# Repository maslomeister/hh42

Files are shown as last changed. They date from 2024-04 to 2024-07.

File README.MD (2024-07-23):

# hh42

Беспроводная эрго сплит клавиатура заточенная под руки владельца репозитория, MX LP и [ZMK](https://zmk.dev/).

Спасибо [Corne](https://github.com/foostan/crkbd) за вдохновление.

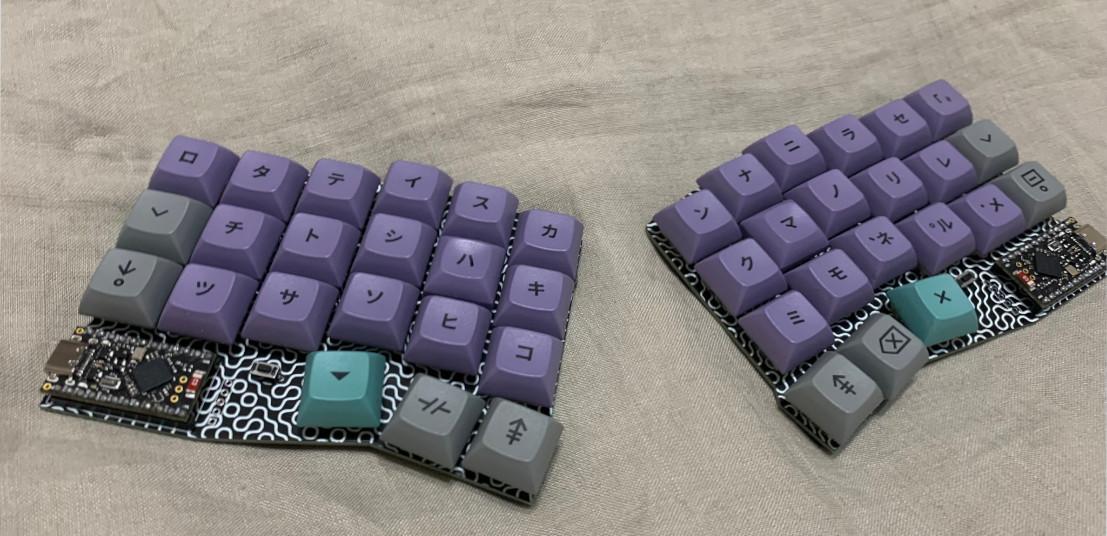
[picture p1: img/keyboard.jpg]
keyboardimage


# Гербер файлы

Скачать гербер файлы ПЦБ можно [ТУТ](https://github.com/maslomeister/hh42/blob/main/pcb/production/hh42.zip)

# Стоимость сборки

| Предмет | Цена в $ | Комментарий | Ссылка |
| --- | --- | --- | --- |
| ПЦБ | 25 | Цена за 5 комплектов | https://aliexpress.ru/item/1005006573905744.html |
| MX LP свитчи | 27 | Цена за 60 штук | https://aliexpress.ru/item/1005006328228130.html |
| Ножки | 4.6 | Цена за 100 штук | https://aliexpress.ru/item/32963141746.html |
| SuperMini | 4.8 | Клон nice nano 2.0 | https://aliexpress.ru/item/1005006035267231.html |
| Диоды | 0.85 | Цена за 100 штук | https://aliexpress.ru/item/32849879904.html |
| PCM12SMTR переключатель | 4 | Цена за 5 штук | https://aliexpress.ru/item/1005005366298406.html |
| Reset кнопка | 1.5 | 4.3ММ; Цена за 100 штук | https://aliexpress.ru/item/32882161197.html |
| Сокеты для контроллера  | 1.9 | Цена за 100 штук | https://aliexpress.ru/item/32980406694.html |
| Пины для контроллера | 4.3 | Цена за 100 штук | https://aliexpress.ru/item/32858430771.html |
| Аккумулятор 110 mah | 4.2 | - | https://www.ozon.ru/product/akkumulyator-dlya-videoregistratora-akb-batareya-3-7v-130mah-5x12x30-li-pol-2-provoda-501230-1047383524 |
| Итог за 1 клавиатуру | <!--5+27+4.6/100*30+4/8+4/8+0.85/100*42+4/5*2+1.5/10*2+1.9/100*48+4.3/100*48+4.2+4.2--> **~48** |

# Прошивка и раскладка

Готовые файлы прошивки [ТУТ](https://github.com/maslomeister/hh42/tree/main/firmwares), репозиторий с исходниками [ТУТ](https://github.com/maslomeister/zmk-configs)

### Основной слой

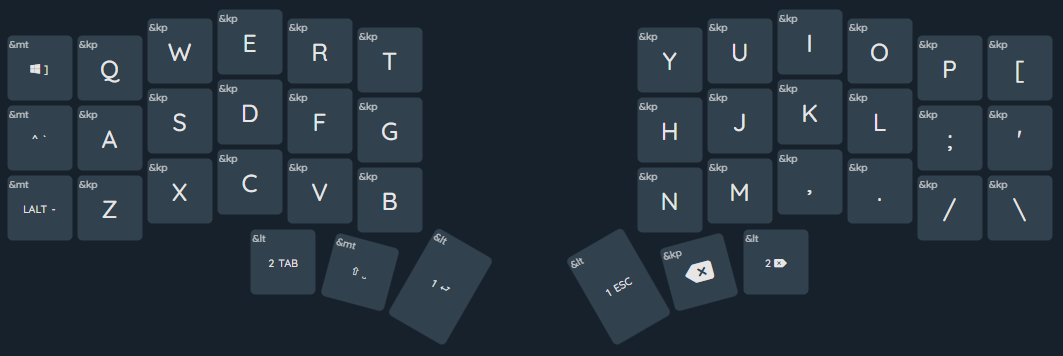
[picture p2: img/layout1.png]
основной_слой


### Lower слой

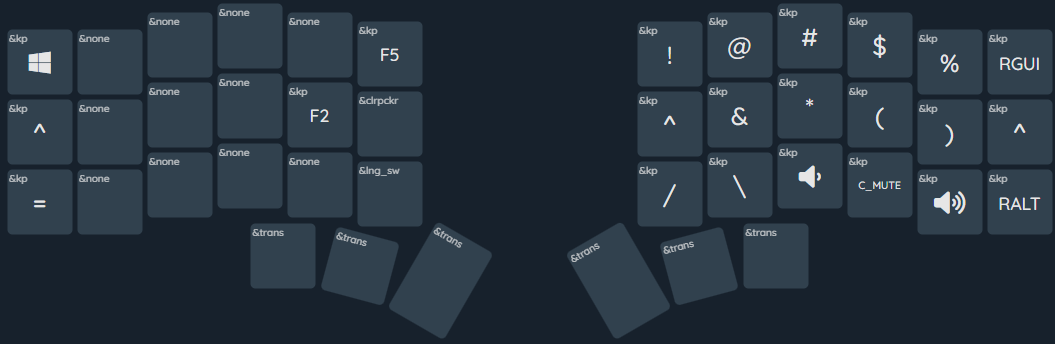
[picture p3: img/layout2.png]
lower_слой


### Raise слой

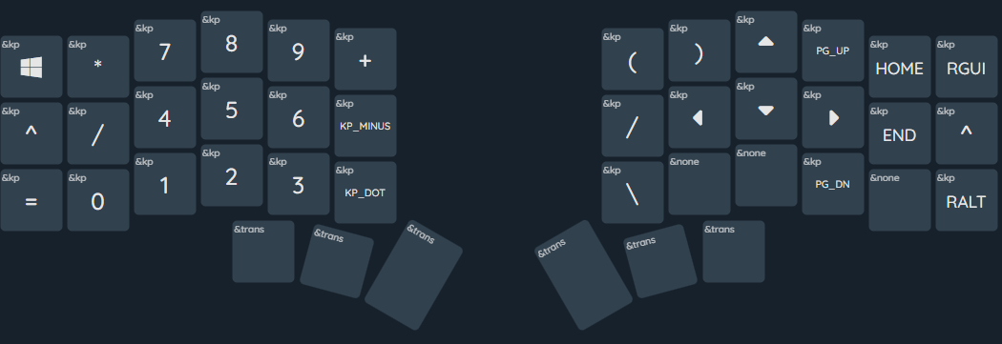
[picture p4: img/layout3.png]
raise_слой


### Combined слой (Lower+Raise)

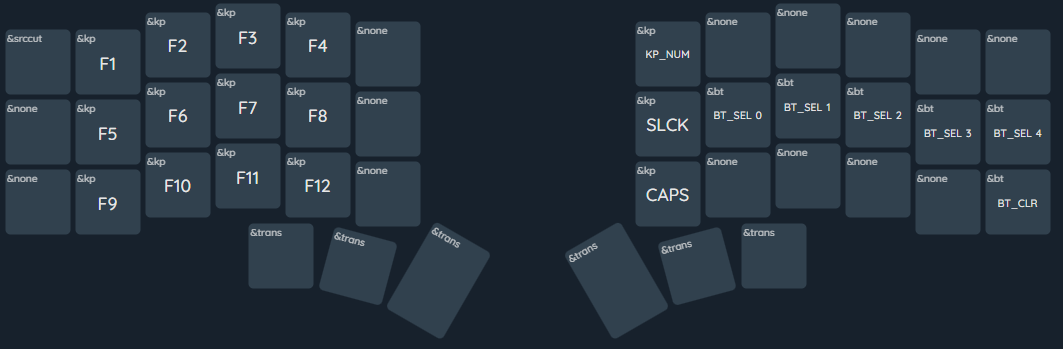
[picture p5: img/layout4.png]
combined_слой


# Сборка

Контроллеры паяются диодами вверх, все остальное видно на шелкографии. Аккумулятор на 110 mah паять к пинам под контроллерами чтобы питание можно было отключать через переключатель.

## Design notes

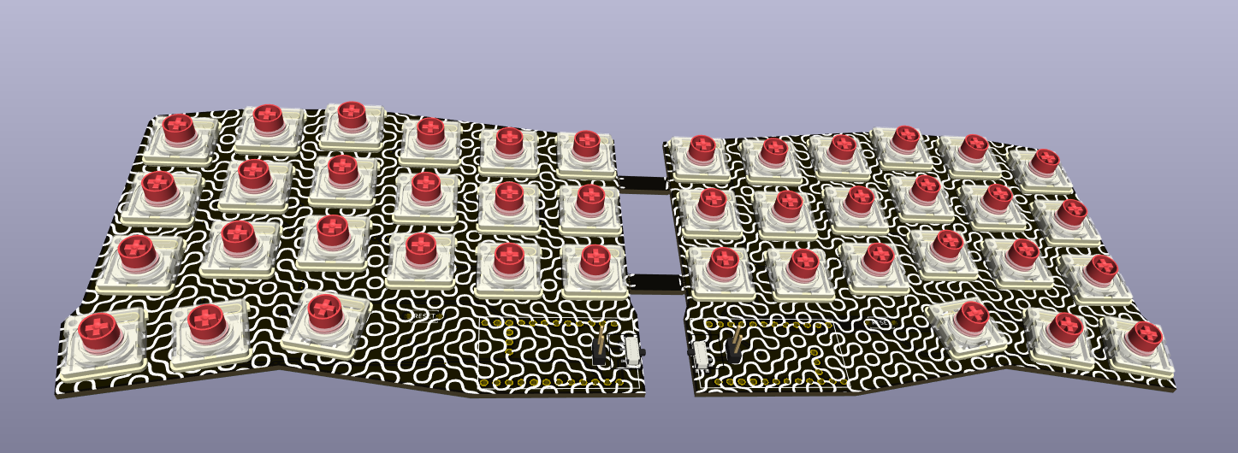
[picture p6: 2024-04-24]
img/kicad_3d.png

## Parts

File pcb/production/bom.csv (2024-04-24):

Designator | Footprint | Quantity | Value | LCSC Part #
D1, D10, D11, D12, D13, D14, D15, D16, D17, D18, D19, D2, D20, D21, D22, D23, D24, D25, D26, D27, D28, D29, D3, D30, D31, D32, D33, D34, D35, D36, D37, D38, D39, D4, D40, D41, D42, D5, D6, D7, D8, D9 | D_SOD123 | 42 | 1N5819WS
J1, J3 | PinHeader_1x02_P2.54mm_Vertical | 2 | Battery
S1, S10, S11, S12, S13, S14, S15, S16, S17, S18, S2, S20, S21, S22, S23, S24, S25, S26, S27, S28, S29, S3, S30, S31, S32, S33, S34, S35, S36, S37, S38, S39, S4, S40, S41, S42, S43, S5, S6, S7, S8, S9 | MXLP | 42 | Keyswitch
S19, S44 | ResetSW | 2 | Keyswitch
SW1, SW2 | SW_SPDT_PCM12 | 2 | DIP
U1, U2 | Nice_Nano_V2 | 2 | Nice_Nano_V2

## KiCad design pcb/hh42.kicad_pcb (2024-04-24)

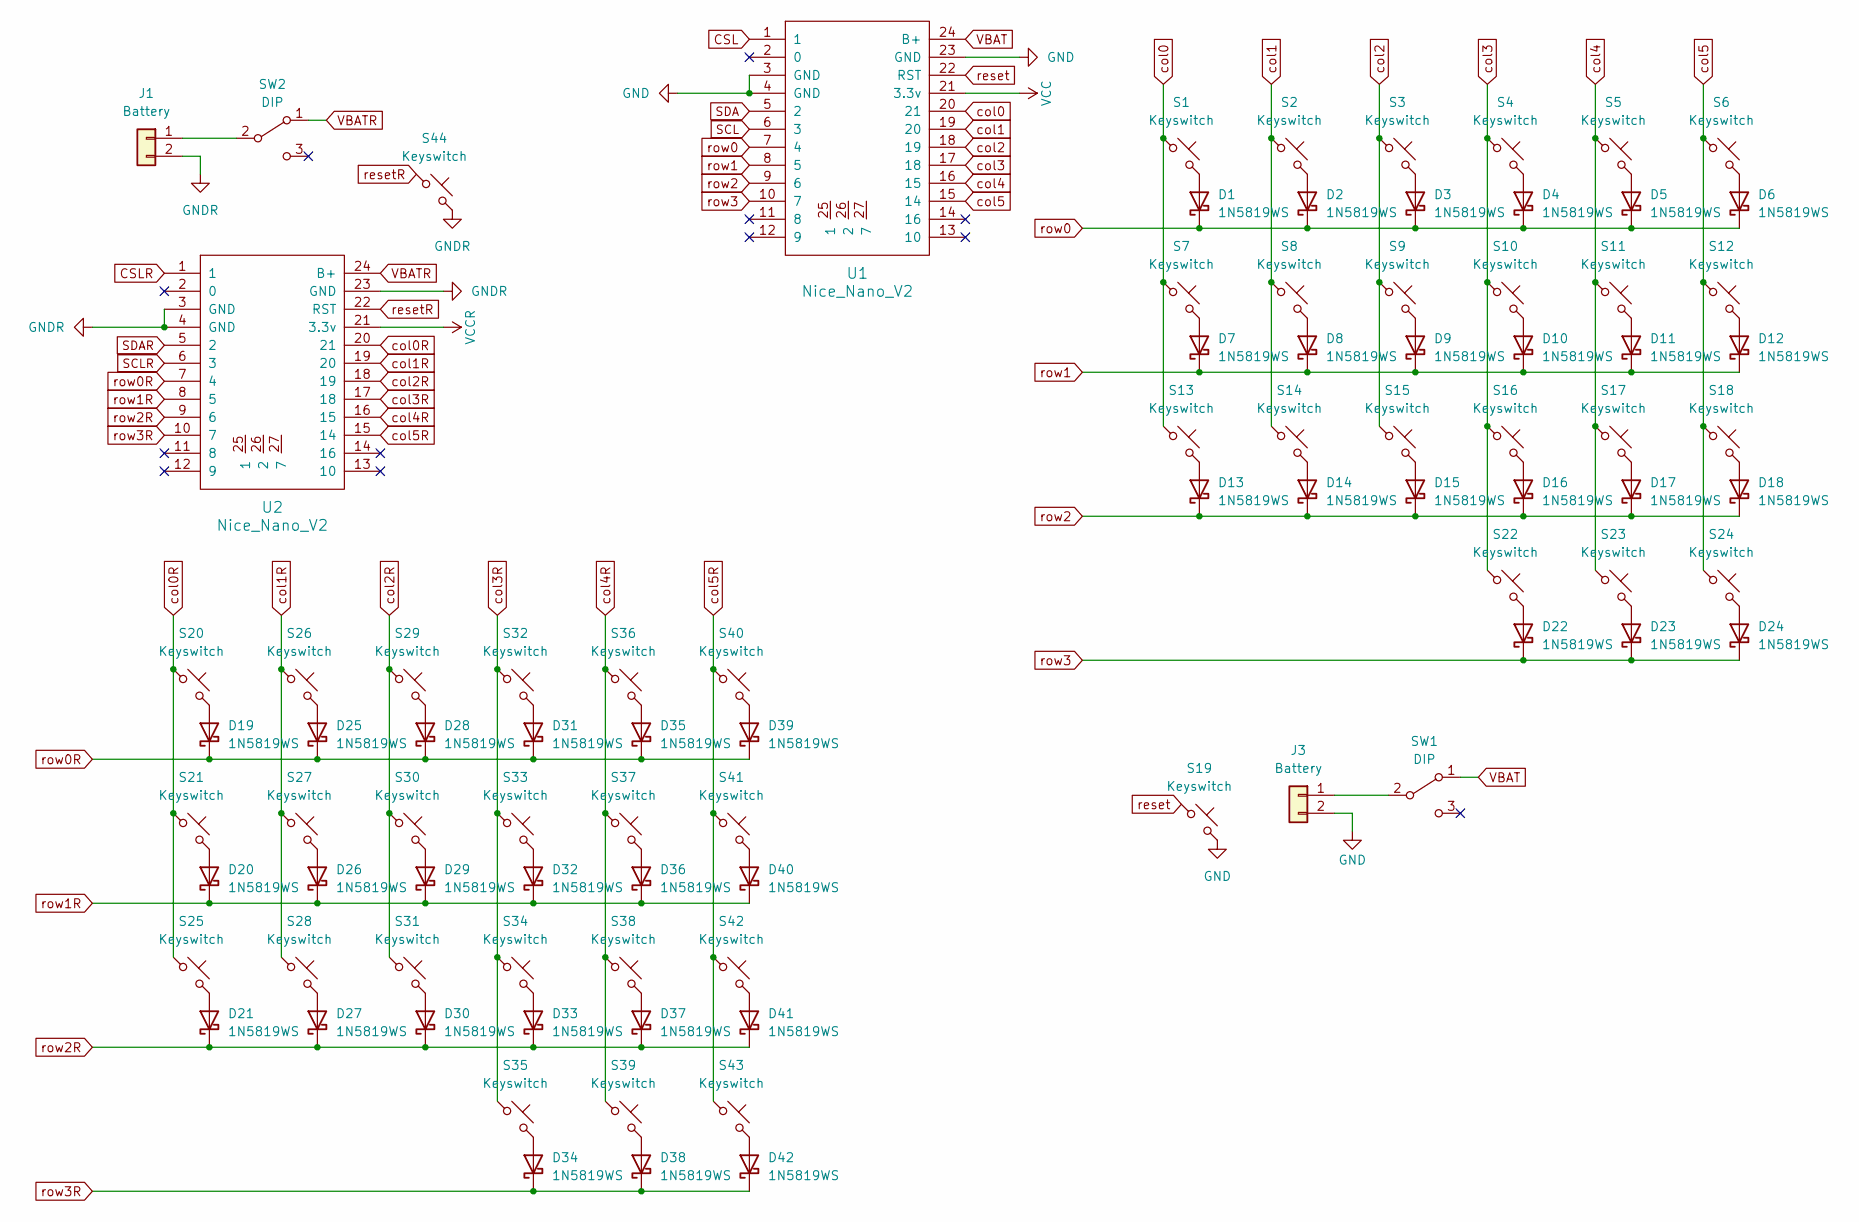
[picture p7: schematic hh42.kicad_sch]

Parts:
D1, D2, D3, D4, D5, D6, D7, D8, D9, D10, D11, D12, D13, D14, D15, D16, D17, D18, D19, D20, D21, D22, D23, D24, D25, D26, D27, D28, D29, D30, D31, D32, D33, D34, D35, D36, D37, D38, D39, D40, D41, D42: 1N5819WS; D_SOD123
J1, J3: Battery; PinHeader_1x02_P2.54mm_Vertical
S1, S2, S3, S4, S5, S6, S7, S8, S9, S10, S11, S12, S13, S14, S15, S16, S17, S18, S20, S21, S22, S23, S24, S25, S26, S27, S28, S29, S30, S31, S32, S33, S34, S35, S36, S37, S38, S39, S40, S41, S42, S43: Keyswitch; MXLP
S19, S44: Keyswitch; ResetSW
SW1, SW2: DIP; SW_SPDT_PCM12; LCSC Part Number C221841
U1, U2: Nice_Nano_V2

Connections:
CSL: U1.1
CSLR: U2.1
GND: J3.2, S19.2, U1.3 (GND), U1.4 (GND), U1.23 (GND)
GNDR: J1.2, S44.2, U2.3 (GND), U2.4 (GND), U2.23 (GND)
unnamed: D1.2 (A), S1.2
unnamed: D2.2 (A), S2.2
unnamed: D3.2 (A), S3.2
unnamed: D4.2 (A), S4.2
unnamed: D5.2 (A), S5.2
unnamed: D6.2 (A), S6.2
unnamed: D7.2 (A), S7.2
unnamed: D8.2 (A), S8.2
unnamed: D9.2 (A), S9.2
unnamed: D10.2 (A), S10.2
unnamed: D11.2 (A), S11.2
unnamed: D12.2 (A), S12.2
unnamed: D13.2 (A), S13.2
unnamed: D14.2 (A), S14.2
unnamed: D15.2 (A), S15.2
unnamed: D16.2 (A), S16.2
unnamed: D17.2 (A), S17.2
unnamed: D18.2 (A), S18.2
unnamed: D19.2 (A), S20.2
unnamed: D20.2 (A), S21.2
unnamed: D21.2 (A), S25.2
unnamed: D22.2 (A), S22.2
unnamed: D23.2 (A), S23.2
unnamed: D24.2 (A), S24.2
unnamed: D25.2 (A), S26.2
unnamed: D26.2 (A), S27.2
unnamed: D27.2 (A), S28.2
unnamed: D28.2 (A), S29.2
unnamed: D29.2 (A), S30.2
unnamed: D30.2 (A), S31.2
unnamed: D31.2 (A), S32.2
unnamed: D32.2 (A), S33.2
unnamed: D33.2 (A), S34.2
unnamed: D34.2 (A), S35.2
unnamed: D35.2 (A), S36.2
unnamed: D36.2 (A), S37.2
unnamed: D37.2 (A), S38.2
unnamed: D38.2 (A), S39.2
unnamed: D39.2 (A), S40.2
unnamed: D40.2 (A), S41.2
unnamed: D41.2 (A), S42.2
unnamed: D42.2 (A), S43.2
unnamed: J1.1, SW2.2 (B)
unnamed: J3.1, SW1.2 (B)
SCL: U1.6 (3)
SCLR: U2.6 (3)
SDA: U1.5 (2)
SDAR: U2.5 (2)
VBAT: SW1.1 (A), U1.24 (B+)
VBATR: SW2.1 (A), U2.24 (B+)
VCC: U1.21 (3.3v)
VCCR: U2.21 (3.3v)
col0: S1.1, S7.1, S13.1, U1.20 (21)
col0R: S20.1, S21.1, S25.1, U2.20 (21)
col1: S2.1, S8.1, S14.1, U1.19 (20)
col1R: S26.1, S27.1, S28.1, U2.19 (20)
col2: S3.1, S9.1, S15.1, U1.18 (19)
col2R: S29.1, S30.1, S31.1, U2.18 (19)
col3: S4.1, S10.1, S16.1, S22.1, U1.17 (18)
col3R: S32.1, S33.1, S34.1, S35.1, U2.17 (18)
col4: S5.1, S11.1, S17.1, S23.1, U1.16 (15)
col4R: S36.1, S37.1, S38.1, S39.1, U2.16 (15)
col5: S6.1, S12.1, S18.1, S24.1, U1.15 (14)
col5R: S40.1, S41.1, S42.1, S43.1, U2.15 (14)
reset: S19.1, U1.22 (RST)
resetR: S44.1, U2.22 (RST)
row0: D1.1 (K), D2.1 (K), D3.1 (K), D4.1 (K), D5.1 (K), D6.1 (K), U1.7 (4)
row0R: D19.1 (K), D25.1 (K), D28.1 (K), D31.1 (K), D35.1 (K), D39.1 (K), U2.7 (4)
row1: D7.1 (K), D8.1 (K), D9.1 (K), D10.1 (K), D11.1 (K), D12.1 (K), U1.8 (5)
row1R: D20.1 (K), D26.1 (K), D29.1 (K), D32.1 (K), D36.1 (K), D40.1 (K), U2.8 (5)
row2: D13.1 (K), D14.1 (K), D15.1 (K), D16.1 (K), D17.1 (K), D18.1 (K), U1.9 (6)
row2R: D21.1 (K), D27.1 (K), D30.1 (K), D33.1 (K), D37.1 (K), D41.1 (K), U2.9 (6)
row3: D22.1 (K), D23.1 (K), D24.1 (K), U1.10 (7)
row3R: D34.1 (K), D38.1 (K), D42.1 (K), U2.10 (7)

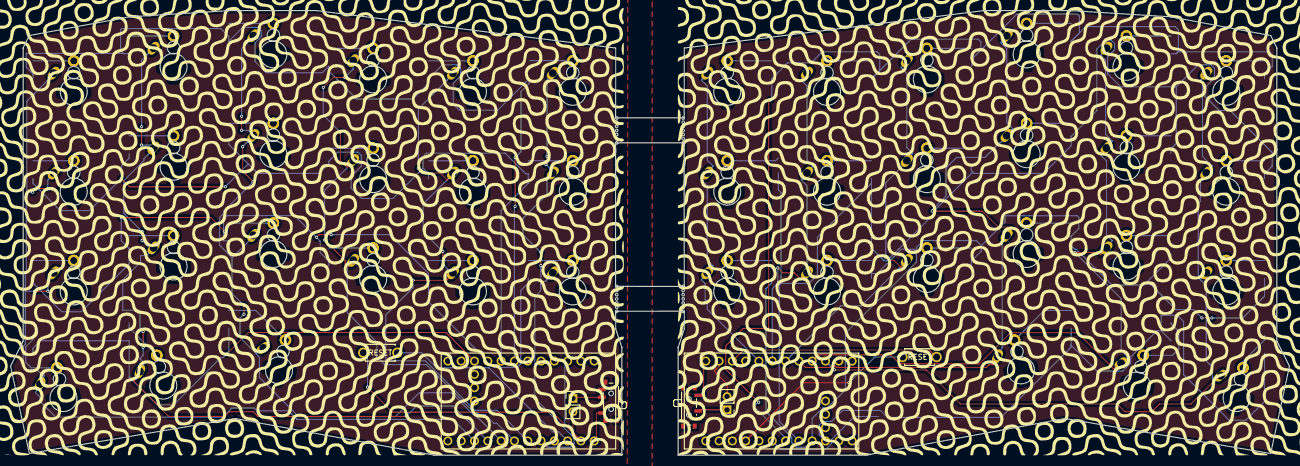
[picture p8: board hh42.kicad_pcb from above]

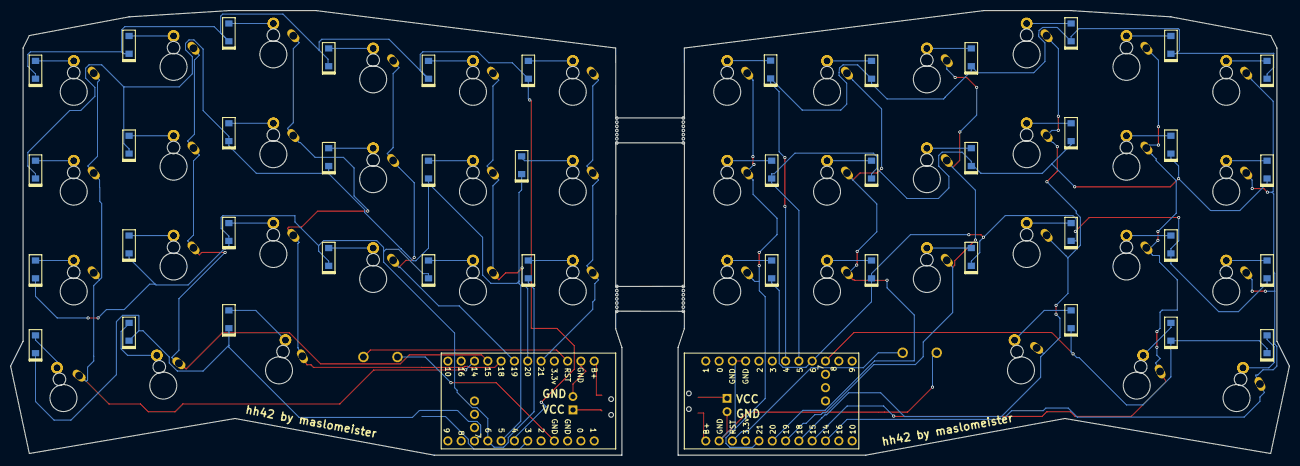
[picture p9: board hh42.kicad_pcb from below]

Board: 2 copper layers, 244.1 x 84.9 mm, 98 parts (42 on the bottom side), 70 nets.

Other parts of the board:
FOREGROUNDL: LOGO; silkscreen_art_inverted
FOREGROUNDR: LOGO; silkscreen_art_inverted
lBT4, lBT42: Breakaway Tabs; Breakaway_Tabs
rBT4, rBT42: Breakaway Tabs; Breakaway_Tabs

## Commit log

2024-04-24 add gerber files
2024-04-24 Add controller mounts and battery
2024-04-24 Добавил сокеты и пины в стоимость
